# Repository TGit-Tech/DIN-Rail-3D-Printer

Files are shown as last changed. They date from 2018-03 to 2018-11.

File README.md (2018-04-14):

# DIN-Rail-3D-Printer
A very large ( 36" x 36" ) 3D Printer assembled with 35x15mm 1-meter Steel DIN Rails

# Progress
This repository is currently a work in progress.  Please check back later for a working model.

- Very first print resulted in issues with build plate tolerance
- Currently waiting for Proximity sensor to test ability to compensate

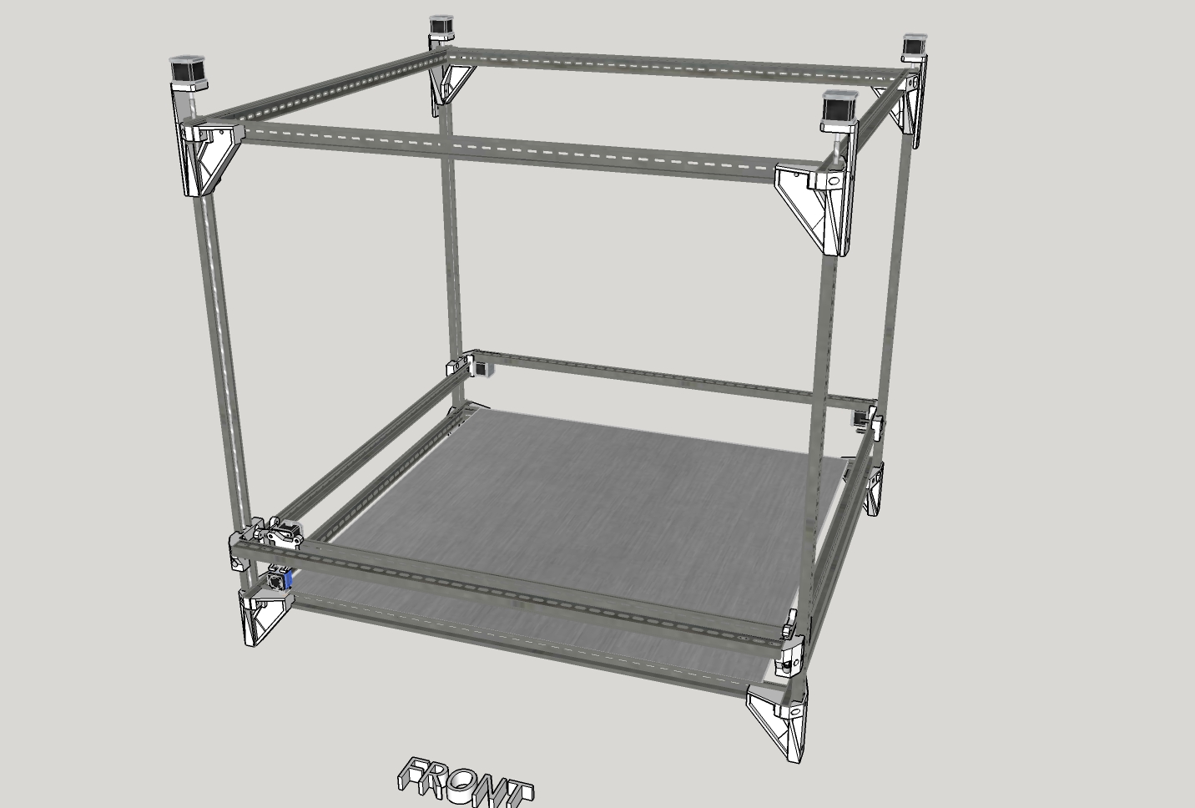
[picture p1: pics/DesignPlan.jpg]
Design Plan

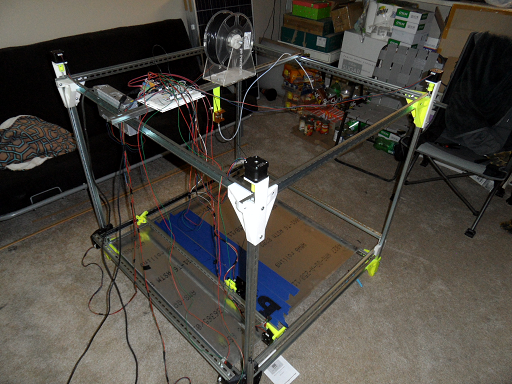
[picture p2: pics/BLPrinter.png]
BLPrinter

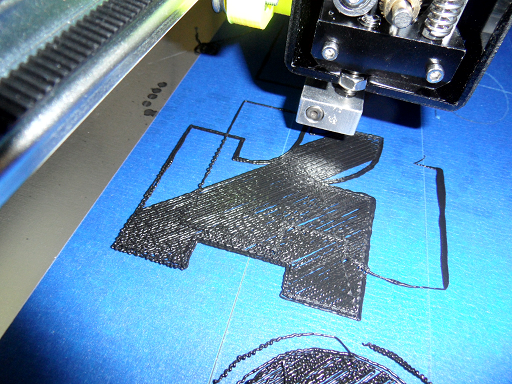
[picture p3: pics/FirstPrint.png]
FirstPrint


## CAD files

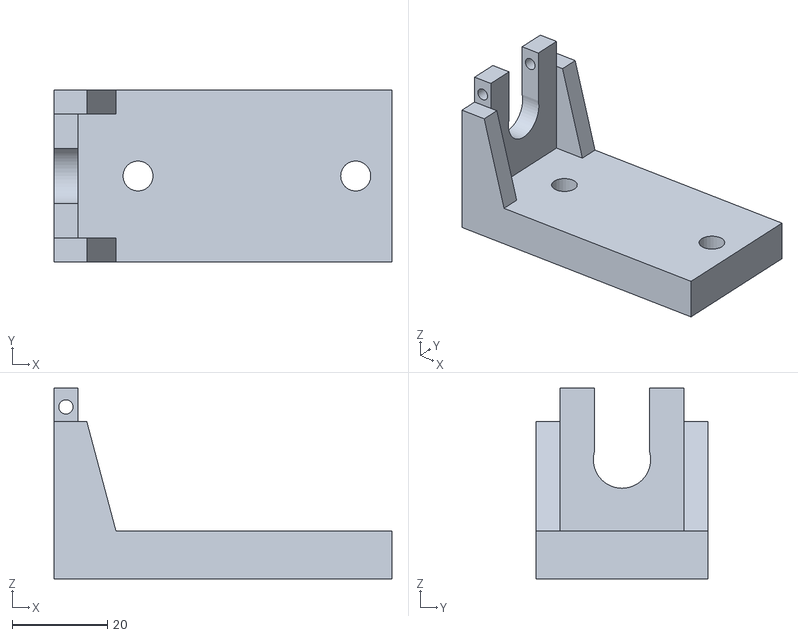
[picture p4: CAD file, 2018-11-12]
3D-Prints-STL/Extruder-Head.stl
70.8 x 36.0 x 40.0

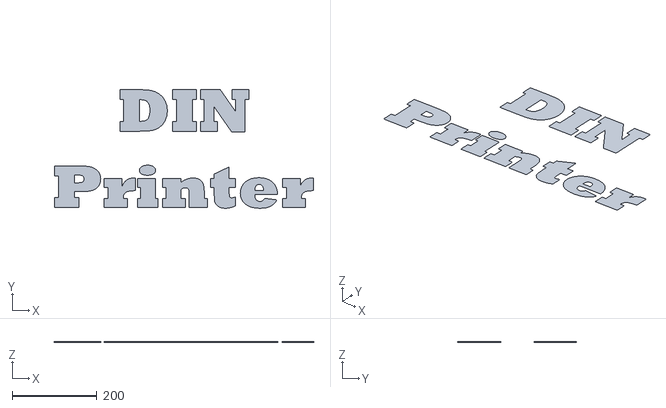
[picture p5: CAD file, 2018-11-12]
Samples/DinPrinter_600mmW.stl
609.9 x 279.6 x 1

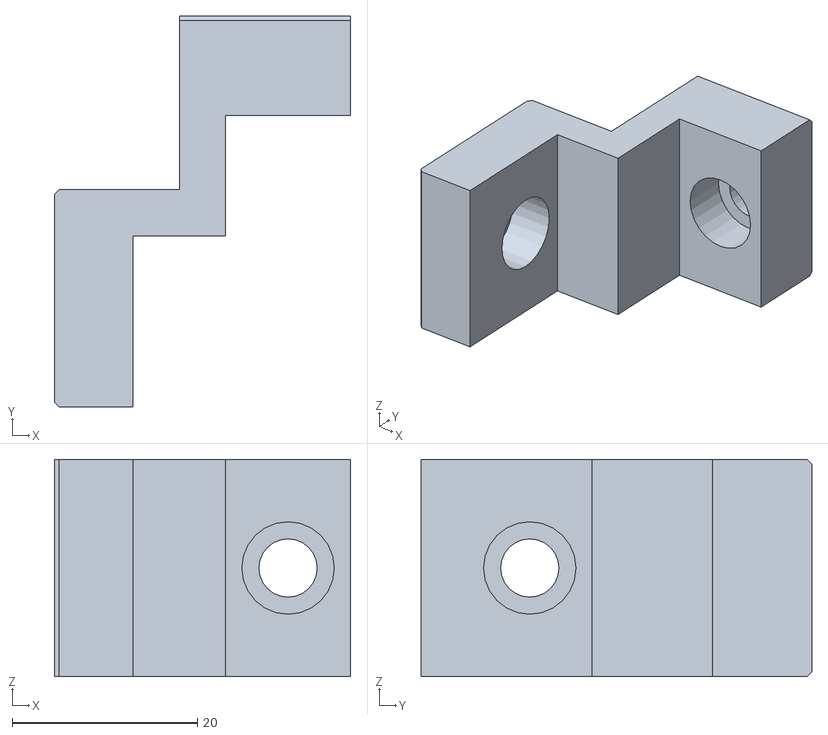
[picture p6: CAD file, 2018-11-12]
3D-Prints-STL/Electronics-DIN-Bracket.stl
32.0 x 42.3 x 23.5

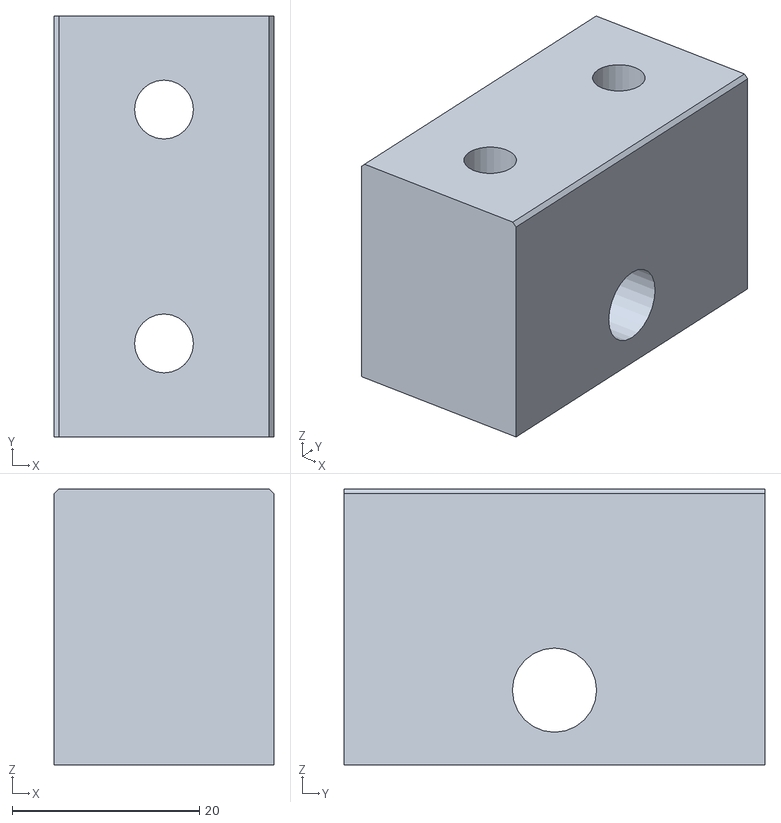
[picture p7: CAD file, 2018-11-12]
3D-Prints-STL/Filament-Spool-Holder.stl
23.5 x 45.0 x 29.5

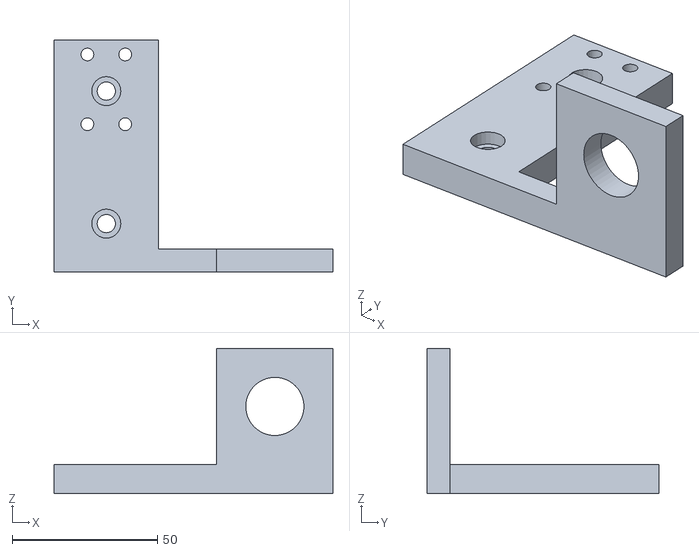
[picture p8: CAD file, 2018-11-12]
3D-Prints-STL/Extruder-Head-AnetA8.stl
96.0 x 79.9 x 50.0

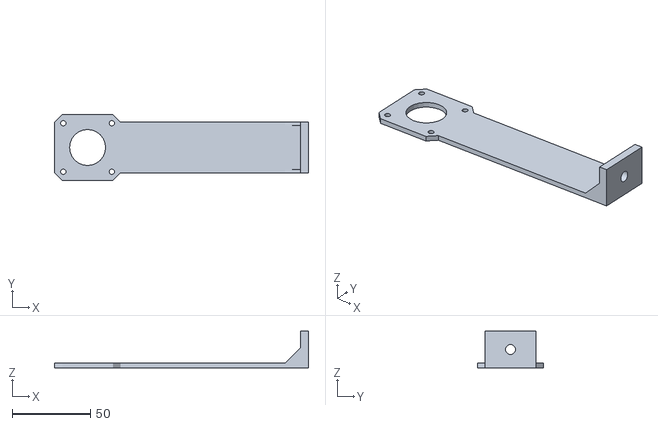
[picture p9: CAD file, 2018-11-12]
3D-Prints-STL/MK8-Extruder-Bracket.stl
162.3 x 42.3 x 23.5

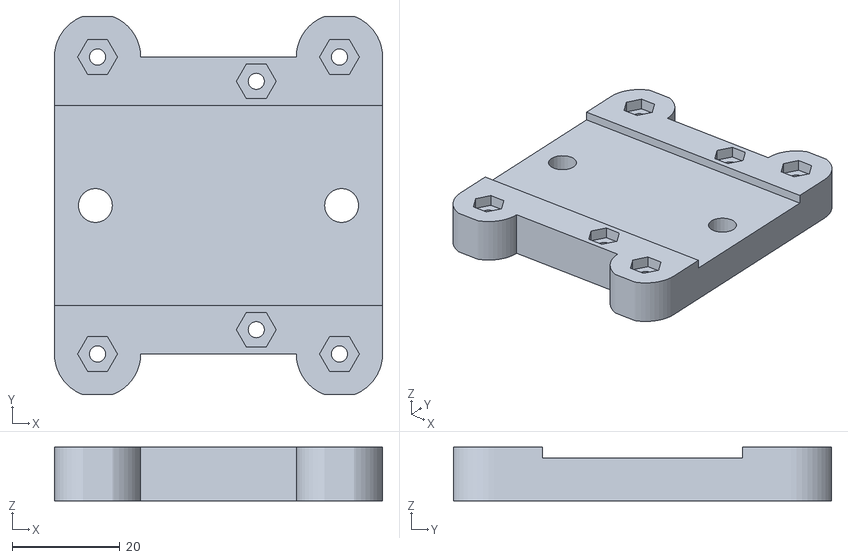
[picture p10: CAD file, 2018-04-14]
3D-Prints-STL/X-Head.stl
60.8 x 70.0 x 10.0

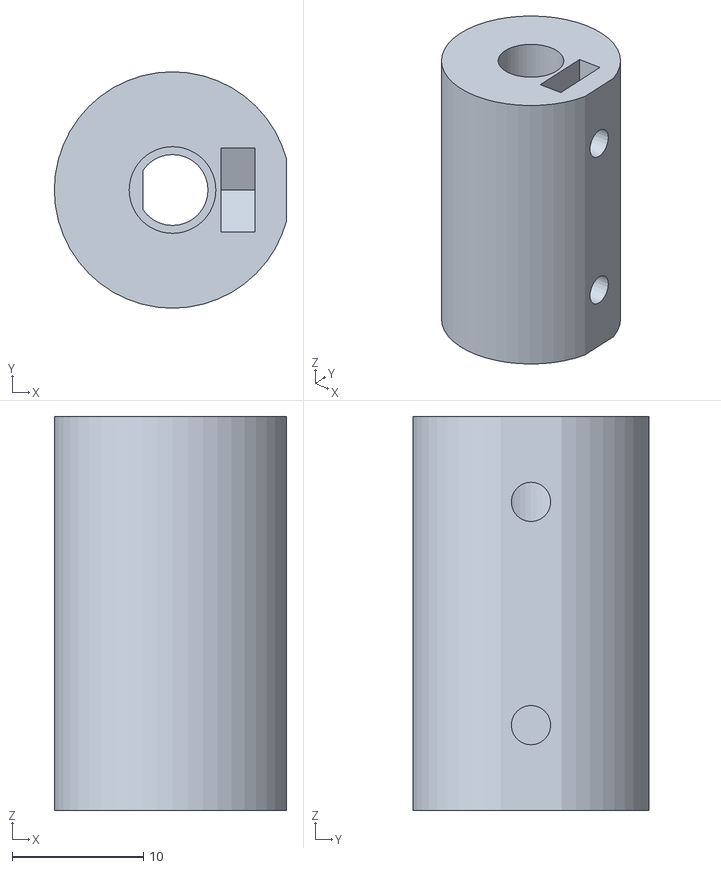
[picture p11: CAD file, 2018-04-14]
3D-Prints-STL/Top-Motor-TieBushing.stl
17.7 x 18.0 x 30.0

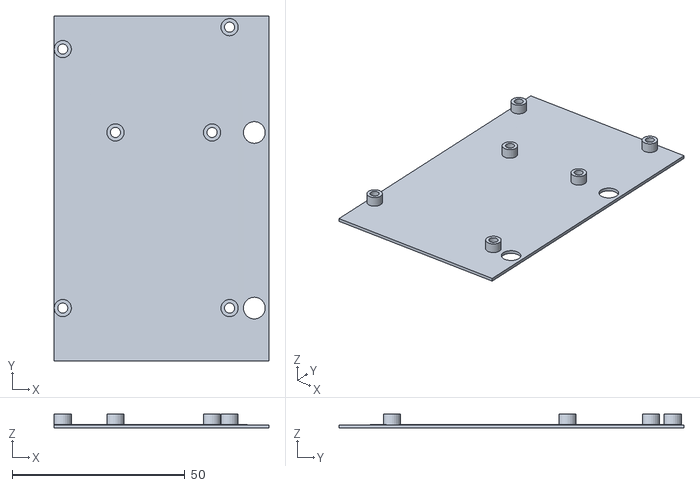
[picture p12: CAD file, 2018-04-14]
3D-Prints-STL/ArduinoMega-MountPlate.stl
62.2 x 99.7 x 4.19

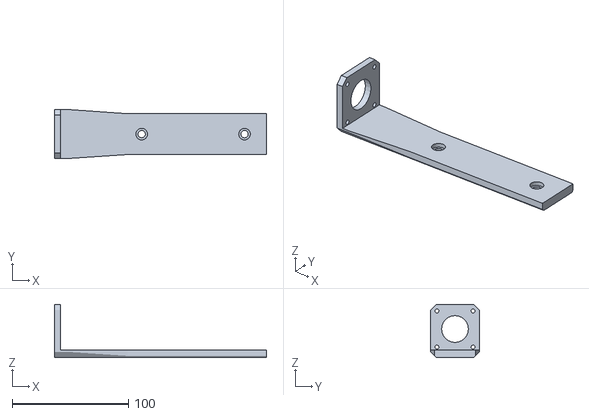
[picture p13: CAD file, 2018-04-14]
3D-Prints-STL/Top-Motor-Clamp-LockNut.stl
182.0 x 42.3 x 45.7

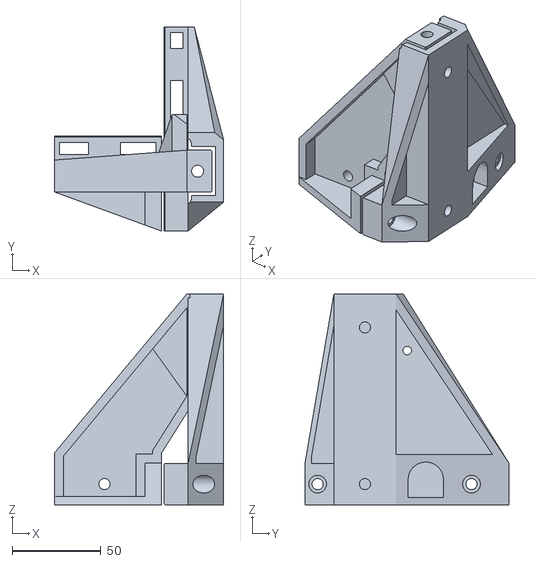
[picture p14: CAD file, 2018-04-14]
3D-Prints-STL/Top-Corner-FlipR.stl
95.4 x 115.0 x 118.9

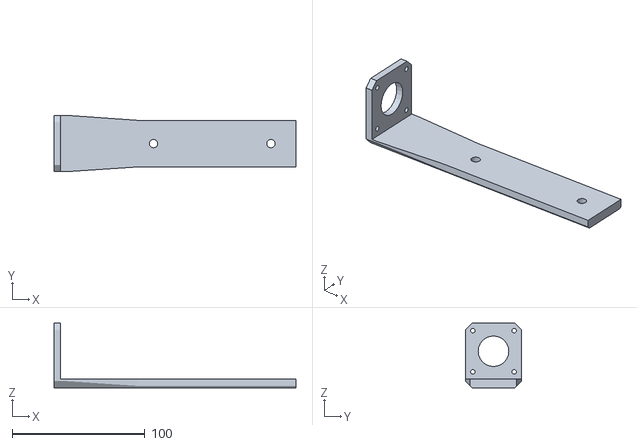
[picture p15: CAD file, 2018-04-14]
3D-Prints-STL/Top-Motor-Clamp.stl
182.0 x 42.3 x 48.7

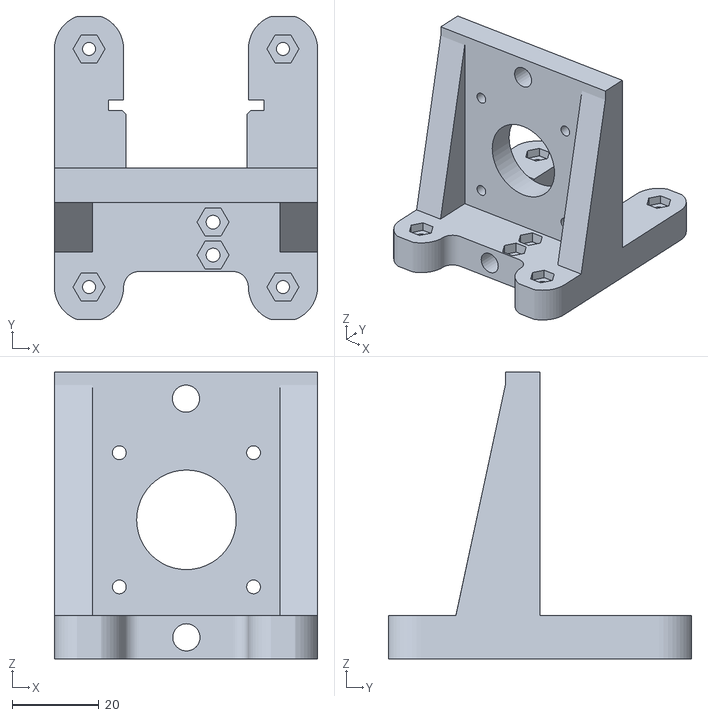
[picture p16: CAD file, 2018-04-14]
3D-Prints-STL/X-Gantry-MotorEnd.stl
60.8 x 70.0 x 66.3

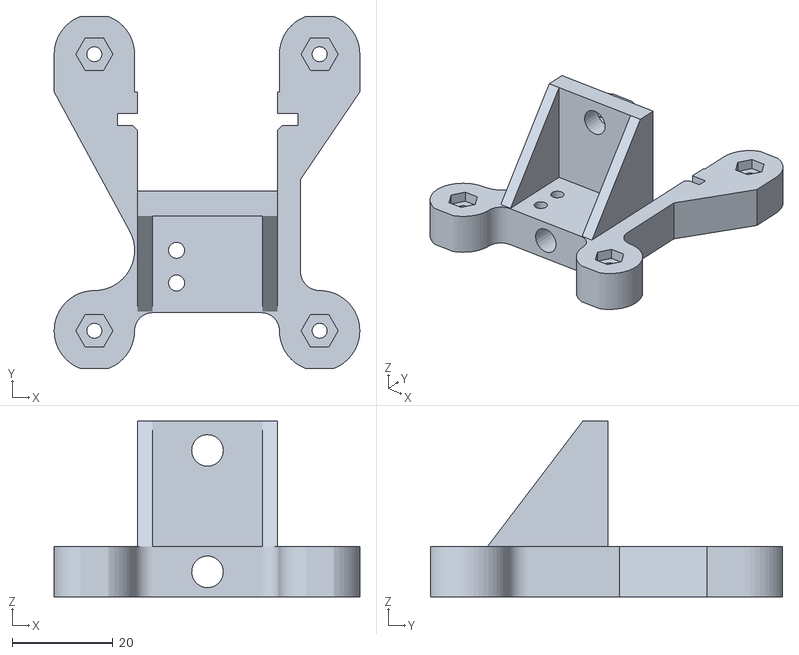
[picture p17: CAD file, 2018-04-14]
3D-Prints-STL/X-Gantry-End.stl
60.8 x 70.0 x 35.0

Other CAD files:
3D-Prints-STL/Top-Corner.stl
3D-Prints-STL/Footing-FlipR.stl
3D-Prints-STL/Footing.stl
3D-Prints-STL/Z-Endstop-Base.stl
3D-Prints-STL/Gantry-Corner-BL-YMotor-FlipR.stl
3D-Prints-STL/Gantry-Corner-BR-YMotor.stl
3D-Prints-STL/Gantry-Corner-FL-YPulley-FlipG.stl
3D-Prints-STL/Gantry-Corner-FR-YPulley.stl
3D-Prints-STL/Top-Center-Rail-End.stl
3D-Prints-STL/Top-Corner-Flipped.stl
3D-Prints-STL/Top-Motor-Gear.stl
3D-Prints-STL/Top-ThreadedRodGear.stl
3D-Prints-STL/X-Motor-Bracket.stl
3D-Prints-STL/Y-Carriage.stl
3D-Prints-STL/Z-Endstop-Bracket.stl
3D-Prints-SketchUp/ArduinoMega-MountPlate.skp
3D-Prints-SketchUp/Electronics-DIN-Bracket.skp
3D-Prints-SketchUp/Extruder-Head-AnetA8.skp
3D-Prints-SketchUp/Extruder-Head.skp
3D-Prints-SketchUp/Filament-Spool-Holder.skp
3D-Prints-SketchUp/Footing-FlipR.skp
3D-Prints-SketchUp/Footing.skp
3D-Prints-SketchUp/Gantry-Corner-BL-YMotor-FlipR.skp
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

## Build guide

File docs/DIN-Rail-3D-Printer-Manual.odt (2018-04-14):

DIN-Rail 3D Printer

With a HUGE 36” x 36” Build Area

Written By: TGit-Tech (02/2018)

Feel free to use: no strings attached (text content only / images respectfully referenced)

Last Updated: 2018.02.04

*** PROJECT IS INCOMPLETE – PLEASE CHECK BACK LATER ***

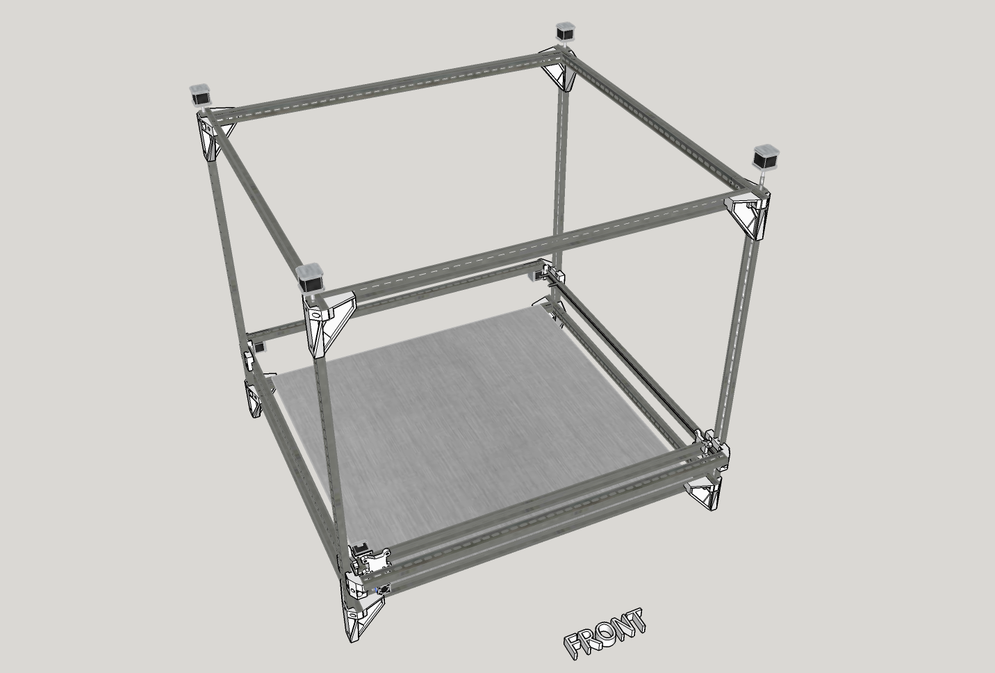
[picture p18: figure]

# INTRODUCTION

The “DIN-Rail 3D Printer” project's goal is to provide a cheap solution to very large 3D printing ability. It will use 1-Meter 35mm DIN Rails.

- The project implements
  - Z-Mobile CoreXY
- The project consists of:
- The project is Open Source and its main page Resides at: https://github.com/TGit-Tech/DIN-Rail-3D-Printer
  - Releases ( All Finalized Plans, Files and Documentation ) can be downloaded at:
  - This document ( most recent version ) can be seen at:

## Materials ($308.74)

#### Framing Hardware ( $262.28 )

- Framing ( $ 258.73 )
  - (20) Steel DIN Rails 35mm W x 15mm H x 1M Length ( DN-R35HS1 ) - $49.50/10pcs = $99
    - https://www.automationdirect.com/adc/Shopping/Catalog/Enclosures_-z-_Subpanels_-z-_Thermal_Management_-z-_Lighting/Enclosure_Parts_-a-_Accessories/Internal_Component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
  - (1) Aluminum Build Plate ( 36” x 36” x 0.188 (3/16”) ) Mill Finish 6061 - $120.00 + $18 Shipping = $138
    - https://www.ebay.com/itm/272758454805
  - (4) Imperial 12650 Metric Threaded Rod M6-1.00x1M ( Pack of 5 ) - $15.81 + $5.92 Shipping = $21.73 ($4.35/ea)
    - https://www.amazon.com/gp/product/B001G4512Q
- Purchase Links
  - M6*30mm Link @ https://www.mcmaster.com/#standard-rounded-head-screws/=1bmfge1
    - Look for Metric STEEL Pan Head Phillips Screws priced @ M6x1mm x 30mm (50) for $6.40
- Bearings ( $3.55 )
  - (20) V-Groove Bearings, Model 603ZZ, 3x12x4mm, Wire Pulley ( 20PCS ( $0.18/ea )) - $3.55
    - Link https://www.aliexpress.com/item/20pcs-set-Professional-Bearing-set-hardware-tools-3-12-4mm-Model-603ZZ-Wire-pulley-with-V/32800396977.html

#### Printer Hardware ($10.52)

- Extrusion ( $ 10.52 )
  - E3D – V6 Long Distance 0.4mm 3D Printer Extruder ( $5.98 )
    - https://www.gearbest.com/3d-printer-parts/pp_613785.html
    - https://www.aliexpress.com/item/Wade-long-distance-V6-J-head-hotend-Extruder-with-cooling-fan-for-1-75mm-3mm-0/32809354646.html
  - MK7 MK8 i3 Extruder Aluminum Block Kit ( $4.54 )
    - https://www.gearbest.com/3d-printer-parts/pp_400612.html?wid=21

#### 3D-Prints & Fasteners ($35.94)

Below is the list of the Parts that need to be printed with a 3D-Printer in the order of assembly; so you can print them in the order shown and assemble them as they finish. Default printer settings are below; but check the per-part details below for any part-specific setting if one may exist .

- Parts were printed on an Anet A8 3D-Printer using Cura with the following settings
  - Layer Height = 0.2
  - Shell Thickness = 1.6
  - Fill Density = 100%
  - Print Speed = 60
  - Support = None
- Suggestions
  - Bed leveling is extra important with any Rack-Gear containing prints -- to ensure a fairly consistent width across the entire tab-out.
  - Use hairspray, tape or any preferred method that keeps large prints on the build plate – uneven builds will cause massive faults.
  - Parts that hold structure are PLA preferred due to its non-curling and non-flexible (brittle) attributes.
    - I've especially been impressed with iFun and PxMallion for cheap structurally sound PLA filament brands
  - Carriage parts are ABS preferred due to their flexible tension-ed slide screws but PLA should work fine.
    - eSun PLA+ filament makes a nice balance between PLA and ABS for such parts.
  - Push all stepper motors towards the drive rail before tightening -- to make a snug gear to rail connection ( reduces slop ).

QTY | Part Picture Part Filename Grams of Filament | Attaches To | Fasteners (!Per-Part!)*QTY | Est. Costs Per-Part PLA Cost @ $15/Kg roll www.boltdepot.com @100-lots | Total Cost
4 | Footing.stl 244-grams PLA preferred | N/A | N/A Base X & Y Rails Top & Bottom Front Right & Back Left | $3.66 Plastic | $14.64
4 | Footing-FlipR.stl 244-grams PLA preferred | N/A | N/A Base X & Y Rails Top & Bottom Front Left & Back Right | $3.66 Plastic | $14.64
| Top-Corner.stl | Z-Rail Top-Y-Rail Top-Y-Rail-End Top-X-Rail Tie-Pieces | (2)#10-24 x 1” Machine Screws & Lock Nuts #10-24 x 1” Machine Screw & Lock Nut #10-24 x 1-1/4” Machine Screw & Nut [$0.02/ea] #10-24 x 1-1/4” Machine Screw & Nut #10-24 x 3/4” Machine Screw & Nut
| Top-Corner-FlipR.stl | Z-Rail Top-Y-Rail Top-Y-Rail-End Tie-Pieces | (2)#10-24 x 1” Machine Screws & Lock Nuts #10-24 x 1” Machine Screw & Lock Nut #10-24 x 1-1/4” Machine Screw & Nut [$0.02/ea] #10-24 x 3/4” Machine Screw & Nut
1 | Gantry-Corner-YMotor.stl 112-grams | Y-Motor (2)Bearings Y-DIN Rail & X-DIN Brace Rail | (4)M3 x 16mm (2)#4-40 x 3/4” Machine Screws [$0.02/ea] (2)#4 Lock Washer (2)#4 Flat Washer (2)#4 Nut (4)#10-24 x 1/2” Machine Screws (4)#10-24 Nuts | $1.68 Plastic | $1.68
1 | Gantry-Corner-YMotor 112-grams | | | $1.68 Plastic | $1.68
1 | Gantry-Corner-YPulley 110-grams | Pulley | M5 * 25mm Machine Screw | $1.65 Plastic | $1.65
1 | Gantry-Corner-YPulley 110-grams | | | $1.65 Plastic | $1.65

- Quick assembly reference pictures
- Settings and Details
  - PLA 1.75mm 3D Plastic Filament was used quoted below at $14.99 per 1-Kg Rolls
  - Original design was printed with an Anet A8 3D-Printer
    - Layer Height: 0.2mm
    - Fill Density: 100%
    - Print speed: 60mm/s
    - Support type: None

#### Electrical ($62.24)

- Stepper Motors ( $70.56 )
  - (8) Nema-17, 2-Phase 1.8-Deg, 3.96V, 0.9A, 4.4Ohm, 5mm Shaft, 42-Stepper Motor - $7.78/ea = $98.70
  - Optional Purchases
    - Anet Brand
      - Purchase link https://www.gearbest.com/3d-printer-parts/pp_540282.html
      - Holding Torque (Metric) - 0.34Nm, 34N.cm, 3467g.cm, 0.0346kg.m, 3.467kg.cm
      - Holding Torque (Standard) - 48oz.in, 0.25lb.ft
      - Product Weight – 0.2610kg, Size 3.5x4x4cm ( 1.38”x1.57”x1.57” )

(https://www.aliexpress.com/item/5pcs-4-lead-Nema17-Stepper-Motor-42-motor-Nema-17-motor-42BYGH-40MM-1-7A-17HS4401/32376023464.html)

    - SingaSong 17HS4401 w/1M cables - $38.88/5pcs - $7.78/ea = $62.24
      - https://www.aliexpress.com/item/5pcs-4-lead-Nema17-Stepper-Motor-42-motor-Nema-17-motor-42BYGH-40MM-1-7A-17HS4401/32376023464.html
      - 2-Phase, 1.8-Deg, 3.8V, 1.7A, 1.5Ohm, 4.2mH
      - Holding Torque (Metric) – .40Nm, 40N.cm, 4000g.cm
      - Length – 40mm, Weight - 280g
- Electronics ( $70.56 )

# Assembly

Top-Corner must be bolted to Rail BEFORE the threaded rod is installed! ( Actually rod will push out of the way if needed as long as the Sub-Assembly is pushed down far enough to allow the rod to bend )

Install Gantry-Corners on a Rail BEFORE tightening the bearing bolts

( 2. Assembly :: Assembly :: Assembly ) Page -5-

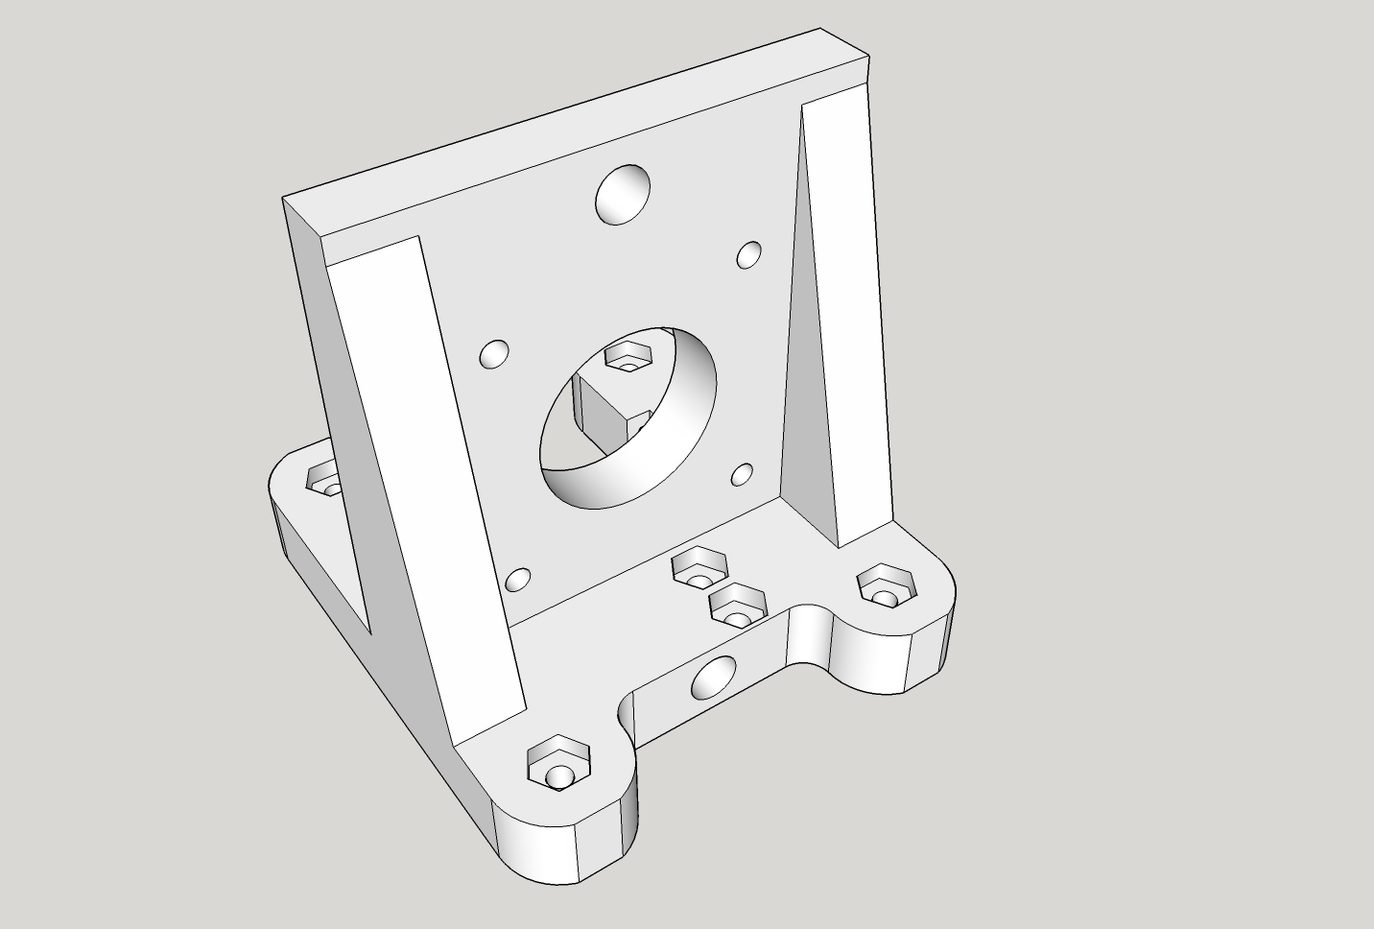
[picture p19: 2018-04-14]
3D-Prints-JPG/X-Gantry-MotorEnd.png

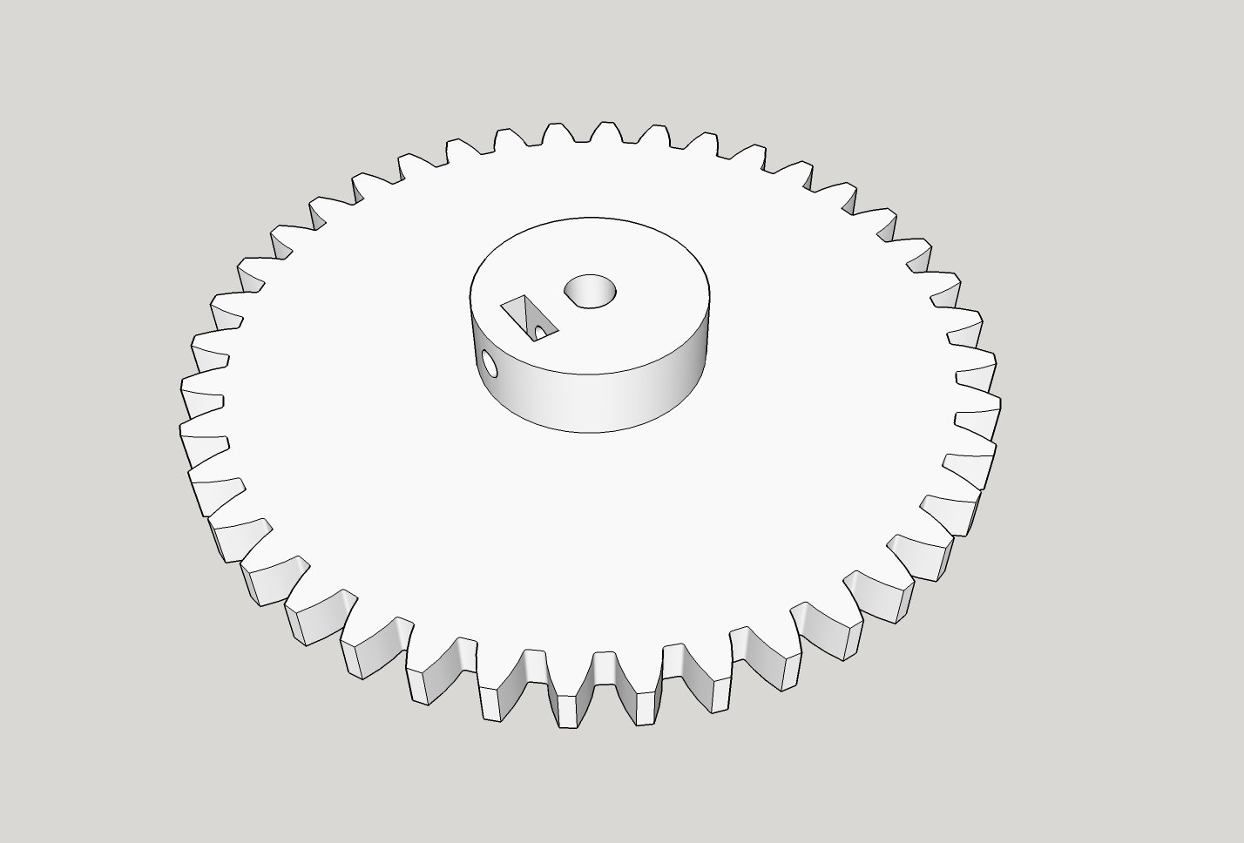
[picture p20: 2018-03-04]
3D-Prints-JPG/Top-Motor-Gear.png

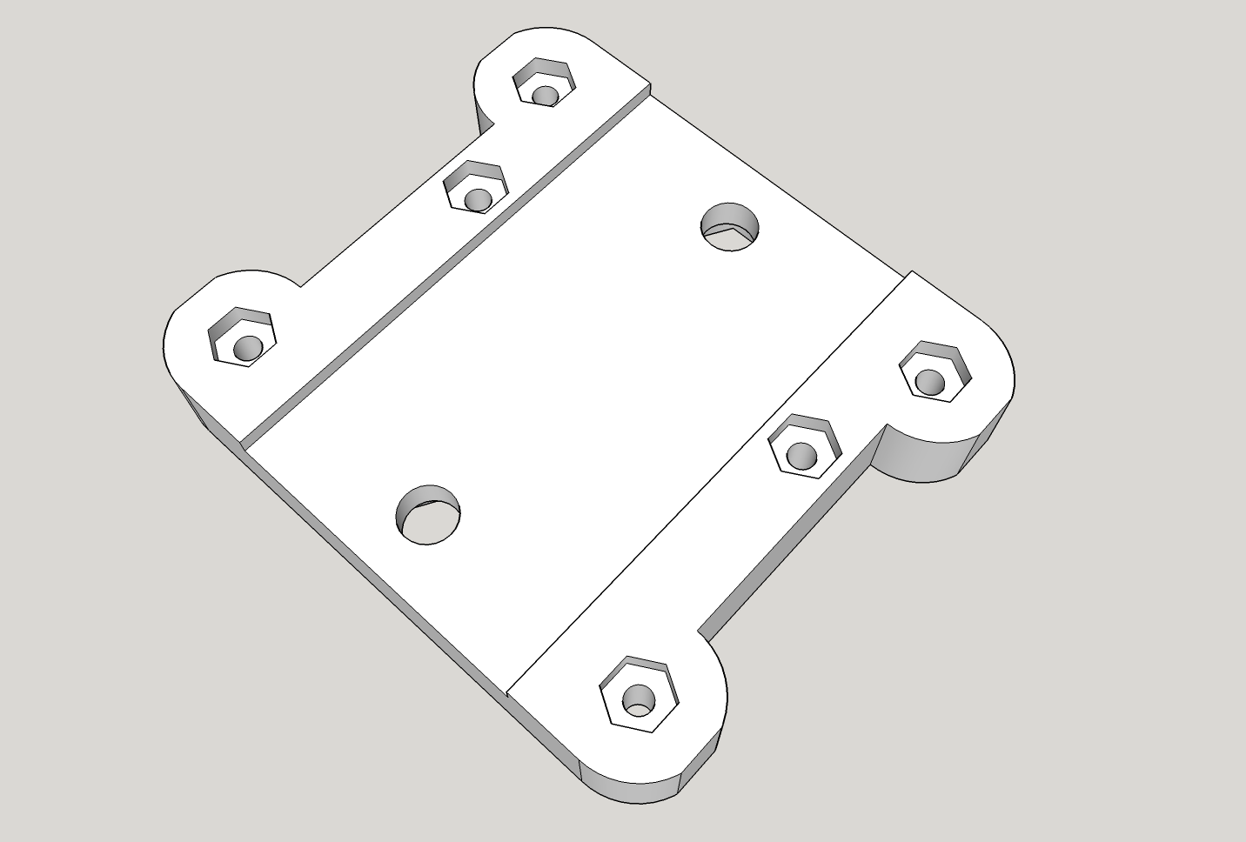
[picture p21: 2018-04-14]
3D-Prints-JPG/X-Head.png

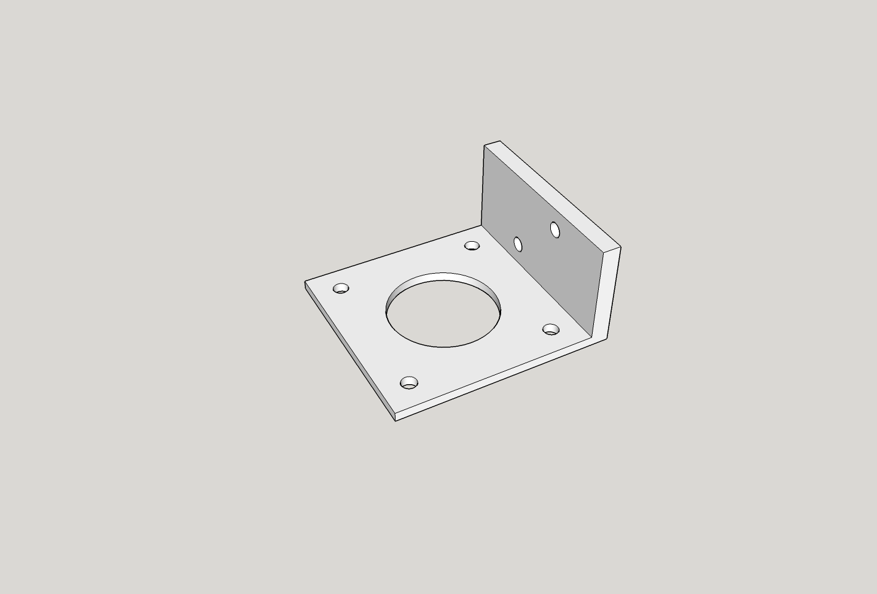
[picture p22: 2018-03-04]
3D-Prints-JPG/X-Motor-Bracket.png

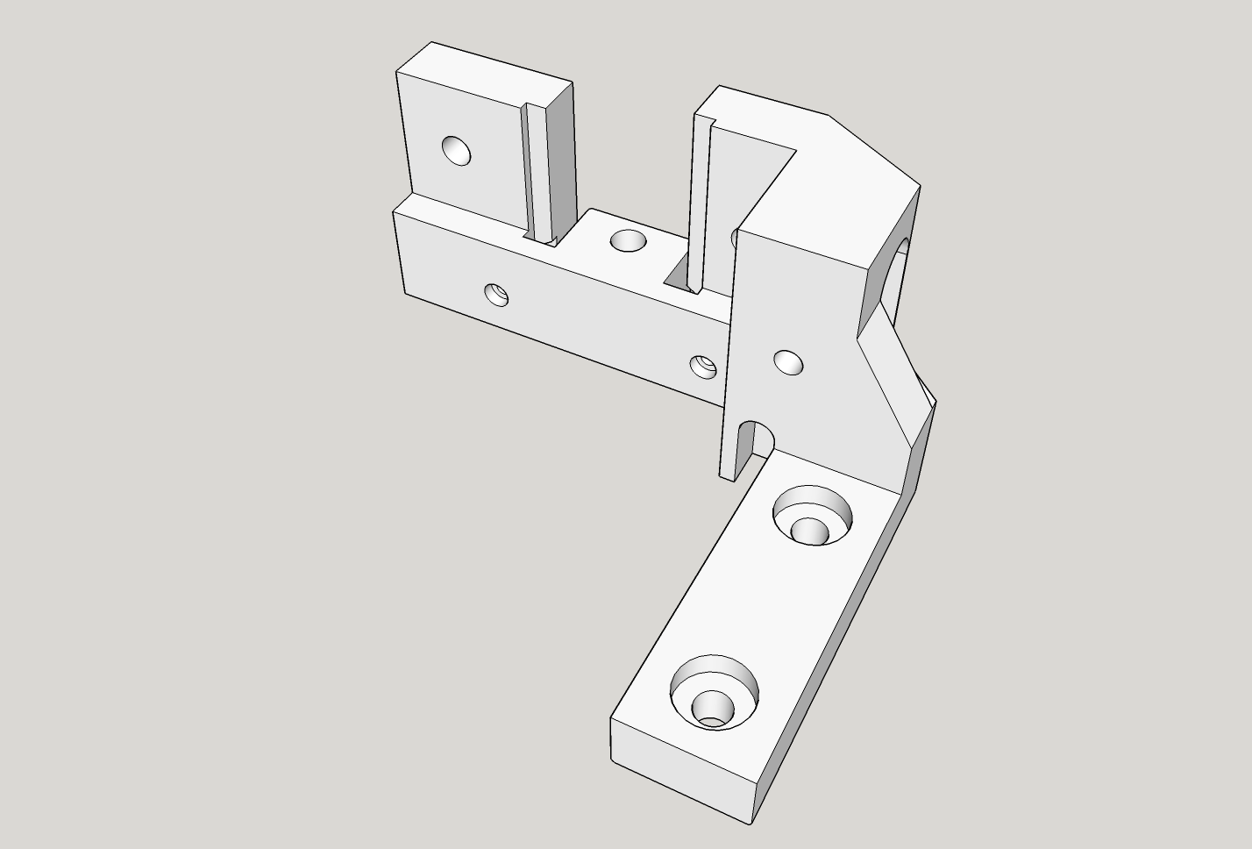
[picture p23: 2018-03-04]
3D-Prints-JPG/Gantry-Corner-YPulley.png

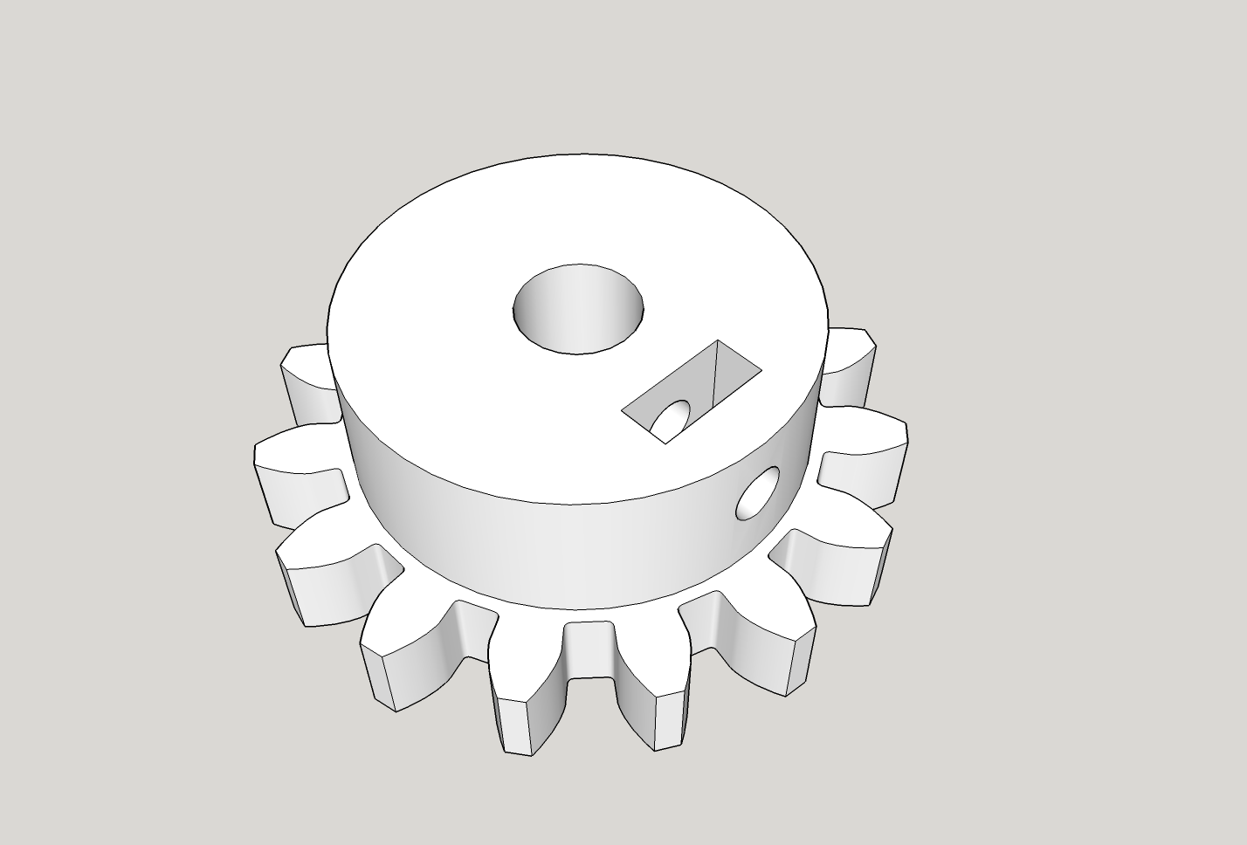
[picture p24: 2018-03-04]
3D-Prints-JPG/Top-ThreadedRodGear.png

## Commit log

2018-02-14 Updates - Still WIP
    [Base-Inner-Corner-Flipped.skp, Base-Inner-Corner-Flipped.stl, Base-Inner-Corner.skp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]
2018-03-04 Update - Still WIP
    [Base-Inner-Corner.stl, Base-Outer-Corner-Flipped.stl, Base-Outer-Corner.stl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]
2018-04-14 First print models
    [ArduinoMega-MountPlate.skp, ArduinoMega-MountPlate.stl, Base-Inner-Corner-Flipped.skp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]
2018-11-12 Updated models
    [DinPrinter_600mmW.skp, DinPrinter_600mmW.stl, Electronics-DIN-Bracket.skp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]
